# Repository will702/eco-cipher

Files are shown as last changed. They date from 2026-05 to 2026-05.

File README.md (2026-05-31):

# Eco-Cipher Edge Verifier

Eco-Cipher Edge Verifier is a prototype hardware-to-platform package for turning factory waste, emission, and energy readings into trusted digital evidence.

The repository contains the full demo stack:

- Hardware blueprint and wiring specs for an ESP32 edge device.
- Arduino firmware for local sensor reading, validation, hashing, and upload.
- CAD and enclosure assets for the physical verifier.
- A Vite React dashboard that explains the proof flow, hardware, matching, settlement, and reporting story.
- Documentation for IoT behavior, ERP integration, and dashboard operation.

## System Flow

```text
Wastewater / emission / energy sample
-> Sensors
-> ESP32 Edge Verifier
-> Local validation
-> OLED, LEDs, buzzer
-> Hashed JSON payload
-> Backend / dashboard
-> Proof ledger
-> AI matchmaker
-> Settlement and reporting
-> ERP adapter
```

The device is designed to make the physical stream auditable before Eco-Cipher uses it for AI matching or compliance reporting.

## Repository Structure

| Path | Purpose |
|---|---|
| `context/` | Source specification: hardware blueprint, wiring, validation rules, payload schema, CAD dimensions, demo flow, and shopping list |
| `firmware/EcoCipherEdgeVerifier/` | ESP32 Arduino firmware |
| `cad/` | OpenSCAD and FreeCAD source/generator files |
| `cad/generated/` | Generated CAD outputs when present |
| `dashboard/` | Vite React dashboard |
| `dashboard/src/` | Dashboard application source |
| `dashboard/public/models/` | Static 3D model assets for the hardware view |
| `docs/` | Human-readable system documentation |
| `PRODUCT.md` | Product context for the dashboard and demo story |
| `DESIGN.md` | Design direction for the dashboard interface |

## Documentation

Start with these docs depending on what you need:

| Document | Use it for |
|---|---|
| [`docs/iot-system-overview.md`](docs/iot-system-overview.md) | Understanding the ESP32 device, sensors, validation, payload, hash, and upload flow |
| [`docs/erp-integration-flow.md`](docs/erp-integration-flow.md) | Understanding how Eco-Cipher should connect to ERP through a backend adapter |
| [`docs/dashboard-flow.md`](docs/dashboard-flow.md) | Understanding the dashboard views, proof stages, scenarios, and operator flow |
| [`context/README.md`](context/README.md) | Original hardware blueprint package overview |
| [`context/04_payload_schema.json`](context/04_payload_schema.json) | Current example payload shape |

## Hardware Summary

The MVP Edge Verifier uses:

- ESP32 DevKit V1
- pH sensor
- Turbidity sensor
- Water flow sensor
- DS18B20 waterproof temperature sensor
- Optional MQ-135 gas sensor
- Optional ACS712/PZEM current or energy sensor
- OLED I2C display
- Green, yellow, and red LEDs
- Buzzer
- Push button
- Industrial enclosure and pipe/sample chamber demo setup

The ESP32 classifies readings into:

| Status | Meaning | Local output |
|---|---|---|
| `VERIFIED` | Sensor readings are inside the clean demo band | Green LED, buzzer off |
| `WARNING` | Readings are usable but carry caution | Yellow LED, short beep |
| `ANOMALY` | Severe threshold breach, zero flow, sensor risk, or missing context | Red LED, repeated buzzer |

## Dashboard

The dashboard is a Vite React application in `dashboard/`. It simulates the platform view of the device and includes:

- proof-stage walkthrough: Sense, Validate, Hash, Upload, Match, Report
- live sensor-style values and status classification
- mock upload payload
- proof ledger/evidence views
- CAD-backed hardware inspection view
- AI receiver matching
- exchange/settlement consequence
- compliance and MRV-style reporting output

Available dashboard views:

```text
overview
edge-ai
hardware
matchmaker
zkgrid
exchange
proofs
reports
```

The hardware view is directly addressable with:

```text
http://127.0.0.1:5173/?view=hardware
```

## Development Commands

Run repository shell commands through `rtk`.

Dashboard commands are run from `dashboard/`:

```bash
rtk bun install
rtk bun run dev --host 127.0.0.1
rtk bun run build
rtk bun run preview
```

If the local shell picks an old Node runtime, use Node 22 before running Bun/Vite commands. A previously verified local Node path was:

```bash
/Users/willson/.nvm/versions/node/v22.21.1/bin
```

## Firmware

Firmware lives at:

```text
firmware/EcoCipherEdgeVerifier/EcoCipherEdgeVerifier.ino
```

The sketch:

- reads pH, turbidity, flow, temperature, gas, and energy/current context
- calculates status and quality scores
- generates `payload_hash` using SHA-256
- updates OLED, LEDs, and buzzer
- posts JSON to the configured API endpoint

Compile it with Arduino IDE or `arduino-cli` using the ESP32 board package and the required sensor/display libraries.

## CAD

CAD source files live in `cad/`. FreeCAD output can be regenerated when FreeCAD is installed:

```bash
rtk /Applications/FreeCAD.app/Contents/Resources/bin/freecadcmd cad/eco_cipher_freecad_model.py
```

Keep generated CAD artifacts scoped to `cad/generated/`.

## ERP Integration Position

ERP integration should happen through a backend adapter, not directly from the ESP32 or browser UI.

Recommended boundary:

```text
Device payload
-> Eco-Cipher ingestion API
-> validation/proof service
-> ERP adapter
-> ERP records
```

Typical ERP outputs include:

- IoT measurement event
- waste batch or material lot
- quality inspection record
- nonconformance or exception ticket
- receiver recommendation
- transfer or recycling order
- settlement or credit event
- ESG/MRV/compliance report line

See [`docs/erp-integration-flow.md`](docs/erp-integration-flow.md) for the detailed mapping.

## Verification

Minimum checks by subsystem:

| Subsystem | Verification |
|---|---|
| Dashboard | `rtk bun run build` from `dashboard/` |
| Firmware | Compile with Arduino IDE or `arduino-cli` for ESP32 |
| CAD | Regenerate FreeCAD/OpenSCAD outputs and inspect STL/STEP files |
| Docs | Review Markdown rendering and links |

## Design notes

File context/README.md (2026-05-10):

# Eco-Cipher Edge Verifier — Hardware Blueprint Package

This package contains a complete hardware prototype blueprint for **Eco-Cipher Edge Verifier**, the IoT-based physical trust layer for the Eco-Cipher platform.

## Prototype Purpose

Eco-Cipher Edge Verifier captures physical waste/environmental data from industrial output points, validates readings locally at the edge, then sends hashed verified payloads to the Eco-Cipher AI + privacy layer.

## Core MVP Stack

- ESP32 DevKit V1
- pH sensor module
- Turbidity sensor
- Water flow sensor
- DS18B20 waterproof temperature sensor
- OLED I2C display
- Green/yellow/red LED indicators
- Buzzer
- Push button
- Industrial-style enclosure
- Pipe/sample chamber demo setup

## Recommended Build Order

1. Assemble ESP32 + OLED + LEDs.
2. Add pH and turbidity sensors.
3. Add flow sensor and temperature sensor.
4. Implement edge validation rules.
5. Send JSON payload to backend.
6. Generate payload hash.
7. Create CAD enclosure render.
8. Build dashboard integration.
9. Record demo video.
10. Insert photos/renders into BRICS slide deck.

## Final Prototype Statement

Eco-Cipher Edge Verifier is the physical trust layer that verifies waste, energy, and carbon-related data directly from industrial processes before the AI matchmaker and privacy-preserving transaction layer process it.

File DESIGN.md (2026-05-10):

# Eco-Cipher Design Context

## Design Strategy

Use a restrained product UI with industrial neutrals, safety-state color, and clear proof-stage hierarchy. Non-technical users should be able to follow the story in this order: physical reading, local decision, tamper-evident hash, receiver match, proof/report outcome.

## Color

- Canvas: tinted light neutral, not pure white.
- Ink: charcoal/slate neutral, not pure black.
- Verified: muted green.
- Warning: ochre/amber.
- Anomaly: controlled red.
- Accent: rust/safety orange, reserved for active navigation, page transitions, and primary actions.

## Typography

Use a practical sans-serif UI stack for readability and a monospace stack for hashes, pins, scores, and payload fragments. Avoid decorative display type in dashboard controls.

## Components

- Navigation buttons must include a plain-language destination hint and selected-state feedback.
- Scenario buttons must explain what the sample means before the user clicks.
- Status panels should show both machine labels and human meaning.
- Loading, retry, and empty states should be written for a demo audience, not only engineers.

## Motion

Motion should confirm state changes: page switching, proof-stage progress, CAD loading, and button activation. Keep transitions short and respect `prefers-reduced-motion`.

## Responsive Behavior

Desktop can use a persistent left rail and multi-column proof workspace. Tablet and mobile should collapse to a single-column flow with horizontal navigation where needed and no hidden content.

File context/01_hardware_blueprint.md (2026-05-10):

# Eco-Cipher Edge Verifier — Full Hardware Blueprint

## 1. Hardware Architecture

```text
Wastewater / Emission / Energy Sample
        ↓
Sensor Modules
        ↓
ESP32 Edge Controller
        ↓
Edge Validation Logic
        ↓
Local Output: OLED + LED + Buzzer
        ↓
Wireless Transmission: Wi-Fi / MQTT / HTTP
        ↓
Backend / Dashboard
        ↓
AI Matchmaker + ZK Hash Layer
```

## 2. Recommended MVP Hardware

| Component | Purpose |
|---|---|
| ESP32 DevKit V1 | Main controller and Wi-Fi communication |
| pH sensor | Measures acidity/alkalinity of wastewater |
| Turbidity sensor | Measures cloudiness/contamination |
| Water flow sensor | Measures flow rate and estimated volume |
| DS18B20 waterproof sensor | Measures liquid temperature |
| OLED I2C display | Shows live values and status |
| Green LED | Verified status |
| Yellow LED | Warning status |
| Red LED | Anomaly status |
| Buzzer | Alert for anomaly |
| Push button | Manual calibration/demo trigger |

## 3. Physical Demo Layout

```text
[Water Container A]
      ↓
[Pipe / Tube]
      ↓
[Flow Sensor]
      ↓
[pH Probe + Turbidity Sensor Zone]
      ↓
[Output Container]

Nearby:
[Eco-Cipher Edge Verifier Box]
ESP32 + OLED + LED + Buzzer
```

## 4. Core Device Function

The device performs:

1. Sensor acquisition.
2. Edge validation.
3. Local status display.
4. Payload generation.
5. Hash generation.
6. Backend transmission.

## 5. Pitch Explanation

The Eco-Cipher Edge Verifier is installed near a factory’s waste output line. It captures pH, turbidity, flow, and temperature data directly from the physical waste stream. The ESP32 performs edge-level validation to detect abnormal readings or manipulation attempts. Verified data is packaged into a hashed payload and sent to the Eco-Cipher platform as trusted input for AI matchmaking and privacy-preserving exchange.

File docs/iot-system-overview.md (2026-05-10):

# Eco-Cipher IoT Overview

Eco-Cipher uses an edge device called the Edge Verifier to read what is happening in the real world at the factory line. It measures the sample, checks whether the reading looks normal, and sends the result to the platform.

## In Simple Terms

```text
Factory sample
-> Sensors
-> ESP32 device
-> Local check
-> Status light and buzzer
-> Hashed payload
-> Dashboard and backend
```

The device looks at things like:

- pH
- turbidity
- flow
- temperature
- gas risk
- energy or current context

## What The Device Does

The device has three jobs:

1. Read the sensors.
2. Decide whether the stream looks `VERIFIED`, `WARNING`, or `ANOMALY`.
3. Send a digital payload with a hash so the record can be checked later.

It also shows the result locally with:

- a green light for verified
- a yellow light for warning
- a red light and buzzer for anomaly

## Why This Matters

The IoT device is the point where physical evidence becomes digital evidence. That is important because the dashboard and ERP should not guess what happened at the source. They should receive a trusted reading from the edge device.

## What Gets Sent

Each reading becomes one small JSON report with the device ID, factory name, sensor values, status, quality score, and payload hash.

That hash is the fingerprint of the reading. It helps the platform prove that the data has not changed.

## Bottom Line

Eco-Cipher IoT is a trust layer at the edge. It reads the factory signal, checks it locally, and sends a verified record to the rest of the system.

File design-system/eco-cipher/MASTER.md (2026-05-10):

# Design System Master File

> **LOGIC:** When building a specific page, first check `design-system/pages/[page-name].md`.
> If that file exists, its rules **override** this Master file.
> If not, strictly follow the rules below.

---

**Project:** Eco-Cipher
**Generated:** 2026-05-07 00:02:41
**Category:** Financial Dashboard

---

## Global Rules

### Color Palette

| Role | Hex | CSS Variable |
|---|-----|---|
| Primary | `#64748B` | `--color-primary` |
| Secondary | `#94A3B8` | `--color-secondary` |
| CTA/Accent | `#F97316` | `--color-cta` |
| Background | `#F8FAFC` | `--color-background` |
| Text | `#334155` | `--color-text` |

**Color Notes:** Industrial grey + safety orange

### Typography

- **Heading Font:** Cormorant
- **Body Font:** Montserrat
- **Mood:** luxury, high-end, fashion, elegant, refined, premium
- **Google Fonts:** [Cormorant + Montserrat](https://fonts.google.com/share?selection.family=Cormorant:wght@400;500;600;700|Montserrat:wght@300;400;500;600;700)

**CSS Import:**
```css
@import url('https://fonts.googleapis.com/css2?family=Cormorant:wght@400;500;600;700&family=Montserrat:wght@300;400;500;600;700&display=swap');
```

### Spacing Variables

| Token | Value | Usage |
|---|---|---|
| `--space-xs` | `4px` / `0.25rem` | Tight gaps |
| `--space-sm` | `8px` / `0.5rem` | Icon gaps, inline spacing |
| `--space-md` | `16px` / `1rem` | Standard padding |
| `--space-lg` | `24px` / `1.5rem` | Section padding |
| `--space-xl` | `32px` / `2rem` | Large gaps |
| `--space-2xl` | `48px` / `3rem` | Section margins |
| `--space-3xl` | `64px` / `4rem` | Hero padding |

### Shadow Depths

| Level | Value | Usage |
|---|---|---|
| `--shadow-sm` | `0 1px 2px rgba(0,0,0,0.05)` | Subtle lift |
| `--shadow-md` | `0 4px 6px rgba(0,0,0,0.1)` | Cards, buttons |
| `--shadow-lg` | `0 10px 15px rgba(0,0,0,0.1)` | Modals, dropdowns |
| `--shadow-xl` | `0 20px 25px rgba(0,0,0,0.15)` | Hero images, featured cards |

---

## Component Specs

### Buttons

```css
/* Primary Button */
.btn-primary {
  background: #F97316;
  color: white;
  padding: 12px 24px;
  border-radius: 8px;
  font-weight: 600;
  transition: all 200ms ease;
  cursor: pointer;
}

.btn-primary:hover {
  opacity: 0.9;
  transform: translateY(-1px);
}

/* Secondary Button */
.btn-secondary {
  background: transparent;
  color: #64748B;
  border: 2px solid #64748B;
  padding: 12px 24px;
  border-radius: 8px;
  font-weight: 600;
  transition: all 200ms ease;
  cursor: pointer;
}
```

### Cards

```css
.card {
  background: #F8FAFC;
  border-radius: 12px;
  padding: 24px;
  box-shadow: var(--shadow-md);
  transition: all 200ms ease;
  cursor: pointer;
}

.card:hover {
  box-shadow: var(--shadow-lg);
  transform: translateY(-2px);
}
```

### Inputs

```css
.input {
  padding: 12px 16px;
  border: 1px solid #E2E8F0;
  border-radius: 8px;
  font-size: 16px;
  transition: border-color 200ms ease;
}

.input:focus {
  border-color: #64748B;
  outline: none;
  box-shadow: 0 0 0 3px #64748B20;
}
```

### Modals

```css
.modal-overlay {
  background: rgba(0, 0, 0, 0.5);
  backdrop-filter: blur(4px);
}

.modal {
  background: white;
  border-radius: 16px;
  padding: 32px;
  box-shadow: var(--shadow-xl);
  max-width: 500px;
  width: 90%;
}
```

---

## Style Guidelines

**Style:** Dark Mode (OLED)

**Keywords:** Dark theme, low light, high contrast, deep black, midnight blue, eye-friendly, OLED, night mode, power efficient

**Best For:** Night-mode apps, coding platforms, entertainment, eye-strain prevention, OLED devices, low-light

**Key Effects:** Minimal glow (text-shadow: 0 0 10px), dark-to-light transitions, low white emission, high readability, visible focus

### Page Pattern

**Pattern Name:** Horizontal Scroll Journey

- **Conversion Strategy:** Immersive product discovery. High engagement. Keep navigation visible.
28,Bento Grid Showcase,bento,  grid,  features,  modular,  apple-style,  showcase", 1. Hero, 2. Bento Grid (Key Features), 3. Detail Cards, 4. Tech Specs, 5. CTA, Floating Action Button or Bottom of Grid, Card backgrounds: #F5F5F7 or Glass. Icons: Vibrant brand colors. Text: Dark., Hover card scale (1.02), video inside cards, tilt effect, staggered reveal, Scannable value props. High information density without clutter. Mobile stack.
29,Interactive 3D Configurator,3d,  configurator,  customizer,  interactive,  product", 1. Hero (Configurator), 2. Feature Highlight (synced), 3. Price/Specs, 4. Purchase, Inside Configurator UI + Sticky Bottom Bar, Neutral studio background. Product: Realistic materials. UI: Minimal overlay., Real-time rendering, material swap animation, camera rotate/zoom, light reflection, Increases ownership feeling. 360 view reduces return rates. Direct add-to-cart.
30,AI-Driven Dynamic Landing,ai,  dynamic,  personalized,  adaptive,  generative", 1. Prompt/Input Hero, 2. Generated Result Preview, 3. How it Works, 4. Value Prop, Input Field (Hero) + 'Try it' Buttons, Adaptive to user input. Dark mode for compute feel. Neon accents., Typing text effects, shimmering generation loaders, morphing layouts, Immediate value demonstration. 'Show, don't tell'. Low friction start.
- **CTA Placement:** Floating Sticky CTA or End of Horizontal Track
- **Section Order:** 1. Intro (Vertical), 2. The Journey (Horizontal Track), 3. Detail Reveal, 4. Vertical Footer

---

## Anti-Patterns (Do NOT Use)

- ❌ Light mode default
- ❌ Slow rendering

### Additional Forbidden Patterns

- ❌ **Emojis as icons** — Use SVG icons (Heroicons, Lucide, Simple Icons)
- ❌ **Missing cursor:pointer** — All clickable elements must have cursor:pointer
- ❌ **Layout-shifting hovers** — Avoid scale transforms that shift layout
- ❌ **Low contrast text** — Maintain 4.5:1 minimum contrast ratio
- ❌ **Instant state changes** — Always use transitions (150-300ms)
- ❌ **Invisible focus states** — Focus states must be visible for a11y

---

## Pre-Delivery Checklist

Before delivering any UI code, verify:

- [ ] No emojis used as icons (use SVG instead)
- [ ] All icons from consistent icon set (Heroicons/Lucide)
- [ ] `cursor-pointer` on all clickable elements
- [ ] Hover states with smooth transitions (150-300ms)
- [ ] Light mode: text contrast 4.5:1 minimum
- [ ] Focus states visible for keyboard navigation
- [ ] `prefers-reduced-motion` respected
- [ ] Responsive: 375px, 768px, 1024px, 1440px
- [ ] No content hidden behind fixed navbars
- [ ] No horizontal scroll on mobile

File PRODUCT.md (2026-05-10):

# Eco-Cipher Product Context

## Register

product

## Product Purpose

Eco-Cipher is a prototype platform that explains how factory waste, emissions, and energy readings become trusted digital evidence. The dashboard connects the physical Edge Verifier device, local ESP32 validation, payload hashing, AI receiver matching, proof records, smart-contract settlement, and CBAM-style reporting.

## Primary Users

- Non-technical pitch audiences who need to understand the proof story quickly.
- Operators inspecting demo sensor states and device behavior.
- Founders, reviewers, and partners evaluating whether the hardware-to-platform flow is credible.

## Core Jobs

- Show what the Edge Verifier senses and why the status becomes verified, warning, or anomaly.
- Make every navigation button feel like a page switch with clear feedback.
- Explain technical ideas in plain language without hiding the real data model.
- Keep the CAD/hardware view connected to the same proof-stage story as the dashboard.

## Tone

Industrial, credible, calm, and demo-ready. The interface should feel like a product control room for a physical prototype, not a generic SaaS landing page.

## Anti-References

- Decorative crypto/neon visuals.
- Dense technical jargon without plain-language explanation.
- Generic card grids where every panel looks equally important.
- UI controls that do not visibly confirm what changed.

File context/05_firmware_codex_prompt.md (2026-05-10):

# Codex Prompt — ESP32 Firmware

```text
Create ESP32 Arduino firmware for Eco-Cipher Edge Verifier.

Hardware:
- ESP32 DevKit V1
- pH sensor on GPIO34 analog
- turbidity sensor on GPIO35 analog
- water flow sensor on GPIO27 interrupt
- DS18B20 temperature sensor on GPIO4
- OLED I2C SDA GPIO21, SCL GPIO22
- green LED GPIO16
- yellow LED GPIO17
- red LED GPIO18
- buzzer GPIO19
- button GPIO25

Firmware requirements:
- Connect to Wi-Fi
- Read all sensors every 5 seconds
- Calculate flow rate and total volume
- Classify status as VERIFIED, WARNING, or ANOMALY
- Display values on OLED
- Turn on LED based on status
- Beep buzzer for anomaly
- Create JSON payload
- Generate a SHA256 hash from the payload
- Send payload to an HTTP endpoint
- Add clean modular functions and comments
- Include placeholder constants for Wi-Fi SSID, password, and API endpoint
- Make the code easy to modify for Supabase/Firebase/Node backend
```

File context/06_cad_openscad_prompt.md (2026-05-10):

# Codex Prompt — OpenSCAD CAD

```text
Create an OpenSCAD model for Eco-Cipher Edge Verifier.

Requirements:
- Industrial IoT enclosure
- Size 120mm x 80mm x 40mm
- Wall thickness 3mm
- Removable lid
- Four M3 screw holes
- Four internal ESP32 mounting posts
- Front OLED cutout
- Three LED holes labeled VALID, WARNING, ANOMALY
- Side ports labeled PWR, PH, TURB, FLOW, TEMP
- Top engraved label: ECO-CIPHER EDGE VERIFIER
- Small QR/device ID plate area
- Add mounting tabs
- Keep everything parametric
- Make it 3D-printable
- Add comments explaining each module
- Split into modules: body(), lid(), mounting_posts(), front_panel_cutouts(), side_ports(), mounting_tabs()
```

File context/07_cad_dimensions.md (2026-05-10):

# CAD Dimensions and Mechanical Notes

## Main Enclosure

```text
Length: 120 mm
Width: 80 mm
Height: 40 mm
Wall thickness: 3 mm
Lid thickness: 3 mm
Screw hole: M3
Mounting posts: 4
```

## Front Panel

Must include:
- OLED display cutout
- 3 LED holes
- Device label
- QR/device ID sticker zone

Suggested layout:

```text
┌────────────────────────────┐
│ ECO-CIPHER EDGE VERIFIER   │
│ ┌──────────────┐           │
│ │ OLED SCREEN  │           │
│ └──────────────┘           │
│ ● VALID ● WARN ● ANOMALY   │
│ ID: EC-EDGE-001            │
└────────────────────────────┘
```

## Side Panel Ports

```text
PWR
PH
TURB
FLOW
TEMP
```

## Industrial Styling

- Rounded corners
- Mounting tabs
- Cable gland holes
- Visible screw heads
- QR/device ID area
- Label: SENSOR IN → VERIFIED DATA OUT

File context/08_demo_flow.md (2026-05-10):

# Demo Flow — Eco-Cipher Edge Verifier

## Scenario

Anonymous Wastewater Exchange with Carbon Impact Recommendation.

Factory A produces wastewater. The Edge Verifier reads physical parameters and sends verified data to Eco-Cipher. The AI matchmaker identifies Factory B as a compatible receiver. The platform displays a verified, privacy-preserving match.

## Demo Sequence

### Step 1 — Boot

OLED:
```text
BOOTING...
Eco-Cipher Edge
```

### Step 2 — Connect

OLED:
```text
WiFi Connected
Device: EC-EDGE-001
```

### Step 3 — Read

Put sensor into sample liquid.

OLED:
```text
Reading sensors...
```

### Step 4 — Validate

LED status:
```text
Green = verified
Yellow = warning
Red = anomaly
```

### Step 5 — Upload

OLED:
```text
Payload uploaded
Hash generated
```

### Step 6 — Dashboard

Dashboard:
```text
Factory A stream verified
AI match found
Carbon impact estimated
```

## Demo Samples

| Sample | Composition | Expected Result |
|---|---|---|
| A | Clear water | Verified stream |
| B | Water + tea/coffee | Organic/turbid waste |
| C | Water + vinegar/soap | Warning/anomaly |

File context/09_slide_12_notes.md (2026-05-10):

# Slide 12 Notes — IoT Hardware Showcase

## Slide Title

Eco-Cipher Edge Verifier: Physical Trust Layer

## Suggested Layout

Left side:
- Photo/CAD of device
- Labeled hardware components

Right side:
- Sensor → ESP32 → Edge Validation → Backend
- 3 key bullets:
  1. Captures physical waste parameters
  2. Performs edge-level anomaly detection
  3. Sends hashed verified payloads to Eco-Cipher AI

## Caption

The device prevents manual greenwashing by verifying waste data directly from industrial output points.

## Hardware-to-Software Mapping

| Hardware Data | Software Meaning | AI Use |
|---|---|---|
| pH | Chemical characteristic | Waste classification |
| Turbidity | Contamination level | Processing suitability |
| Flow rate | Quantity / volume | Exchange feasibility |
| Temperature | Process condition | Validity context |
| Edge status | Trust level | Match confidence |
| Payload hash | Audit proof | ZK/smart contract reference |

## Pitch Script

The Eco-Cipher Edge Verifier is installed near a factory’s waste output line. It uses pH, turbidity, flow, and temperature sensors to capture real physical data. The ESP32 validates these readings at the edge, detects anomalies, and sends a hashed payload to the Eco-Cipher platform. This turns physical industrial output into trusted input for AI matchmaking and privacy-preserving carbon or material exchange.

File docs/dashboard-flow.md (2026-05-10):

# Eco-Cipher Dashboard Flow

The dashboard is the screen that explains the whole Eco-Cipher story. It shows the device reading, the proof state, the receiver match, and the report outcome.

## Main Story

```text
Sense
-> Validate
-> Hash
-> Upload
-> Match
-> Report
```

That is the normal flow when the sample looks good. If the reading is bad, the dashboard still keeps the evidence, but it blocks or holds the later steps.

## What The Dashboard Shows

- the live device state
- the current sensor values
- the payload hash
- the proof record
- the receiver match
- the settlement result
- the reporting result

## Main Views

- `Overview` shows the full story.
- `Edge Verify` shows how the device decides locally.
- `Hardware CAD` shows the physical device in 3D.
- `AI Matchmaker` shows which receiver fits best.
- `Proof Ledger` shows the public proof record.
- `Settlement` shows the exchange result.
- `Evidence` shows the current hash and proof state.
- `Reports` shows the compliance output.

## How People Use It

The dashboard has two common modes:

- guided mode for demos and presentations
- manual mode for checking sensor changes and operator decisions

It also has preset sample scenarios, such as clean water, organic turbidity, anomaly, emission risk, and energy context.

## Bottom Line

The dashboard is the place where Eco-Cipher makes the system easy to understand. It connects the physical device to the proof trail, the matching logic, and the final report.

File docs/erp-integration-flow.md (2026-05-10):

# Eco-Cipher ERP Integration

Eco-Cipher should connect to ERP through the backend, not straight from the sensor or the dashboard button.

## Simple Flow

```text
Edge device
-> Eco-Cipher backend
-> Proof check
-> ERP adapter
-> ERP record
```

## What The ERP Needs

The ERP system does not need the full sensor story. It needs business-ready records such as:

- a measurement event
- a waste batch or material lot
- an inspection result
- an exception ticket
- a receiver recommendation
- a transfer or recycling order
- a settlement or credit event
- a compliance report line

## How Status Changes ERP Behavior

- `VERIFIED` means the reading can move forward.
- `WARNING` means the reading can move forward, but with caution and operator review if needed.
- `ANOMALY` means the reading should be held, quarantined, or sent to manual review.

## Why The Backend Matters

The backend is the place where Eco-Cipher checks the payload, stores the hash, and decides what is safe to pass on. ERP should only receive the approved result, not raw UI state.

## Bottom Line

ERP is where Eco-Cipher turns trusted evidence into business action. The edge device creates the evidence, the backend validates it, and the ERP system records the outcome.

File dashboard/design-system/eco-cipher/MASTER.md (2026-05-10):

# Design System Master File

> **LOGIC:** When building a specific page, first check `design-system/pages/[page-name].md`.
> If that file exists, its rules **override** this Master file.
> If not, strictly follow the rules below.

---

**Project:** Eco-Cipher
**Generated:** 2026-05-05 03:05:42
**Category:** Smart Home/IoT Dashboard

---

## Global Rules

### Color Palette

| Role | Hex | CSS Variable |
|---|-----|---|
| Primary | `#64748B` | `--color-primary` |
| Secondary | `#94A3B8` | `--color-secondary` |
| CTA/Accent | `#F97316` | `--color-cta` |
| Background | `#F8FAFC` | `--color-background` |
| Text | `#334155` | `--color-text` |

**Color Notes:** Industrial grey + safety orange

### Typography

- **Heading Font:** Fira Code
- **Body Font:** Fira Sans
- **Mood:** dashboard, data, analytics, code, technical, precise
- **Google Fonts:** [Fira Code + Fira Sans](https://fonts.google.com/share?selection.family=Fira+Code:wght@400;500;600;700|Fira+Sans:wght@300;400;500;600;700)

**CSS Import:**
```css
@import url('https://fonts.googleapis.com/css2?family=Fira+Code:wght@400;500;600;700&family=Fira+Sans:wght@300;400;500;600;700&display=swap');
```

### Spacing Variables

| Token | Value | Usage |
|---|---|---|
| `--space-xs` | `4px` / `0.25rem` | Tight gaps |
| `--space-sm` | `8px` / `0.5rem` | Icon gaps, inline spacing |
| `--space-md` | `16px` / `1rem` | Standard padding |
| `--space-lg` | `24px` / `1.5rem` | Section padding |
| `--space-xl` | `32px` / `2rem` | Large gaps |
| `--space-2xl` | `48px` / `3rem` | Section margins |
| `--space-3xl` | `64px` / `4rem` | Hero padding |

### Shadow Depths

| Level | Value | Usage |
|---|---|---|
| `--shadow-sm` | `0 1px 2px rgba(0,0,0,0.05)` | Subtle lift |
| `--shadow-md` | `0 4px 6px rgba(0,0,0,0.1)` | Cards, buttons |
| `--shadow-lg` | `0 10px 15px rgba(0,0,0,0.1)` | Modals, dropdowns |
| `--shadow-xl` | `0 20px 25px rgba(0,0,0,0.15)` | Hero images, featured cards |

---

## Component Specs

### Buttons

```css
/* Primary Button */
.btn-primary {
  background: #F97316;
  color: white;
  padding: 12px 24px;
  border-radius: 8px;
  font-weight: 600;
  transition: all 200ms ease;
  cursor: pointer;
}

.btn-primary:hover {
  opacity: 0.9;
  transform: translateY(-1px);
}

/* Secondary Button */
.btn-secondary {
  background: transparent;
  color: #64748B;
  border: 2px solid #64748B;
  padding: 12px 24px;
  border-radius: 8px;
  font-weight: 600;
  transition: all 200ms ease;
  cursor: pointer;
}
```

### Cards

```css
.card {
  background: #F8FAFC;
  border-radius: 12px;
  padding: 24px;
  box-shadow: var(--shadow-md);
  transition: all 200ms ease;
  cursor: pointer;
}

.card:hover {
  box-shadow: var(--shadow-lg);
  transform: translateY(-2px);
}
```

### Inputs

```css
.input {
  padding: 12px 16px;
  border: 1px solid #E2E8F0;
  border-radius: 8px;
  font-size: 16px;
  transition: border-color 200ms ease;
}

.input:focus {
  border-color: #64748B;
  outline: none;
  box-shadow: 0 0 0 3px #64748B20;
}
```

### Modals

```css
.modal-overlay {
  background: rgba(0, 0, 0, 0.5);
  backdrop-filter: blur(4px);
}

.modal {
  background: white;
  border-radius: 16px;
  padding: 32px;
  box-shadow: var(--shadow-xl);
  max-width: 500px;
  width: 90%;
}
```

---

## Style Guidelines

**Style:** Dark Mode (OLED)

**Keywords:** Dark theme, low light, high contrast, deep black, midnight blue, eye-friendly, OLED, night mode, power efficient

**Best For:** Night-mode apps, coding platforms, entertainment, eye-strain prevention, OLED devices, low-light

**Key Effects:** Minimal glow (text-shadow: 0 0 10px), dark-to-light transitions, low white emission, high readability, visible focus

### Page Pattern

**Pattern Name:** Hero + Testimonials + CTA

- **Conversion Strategy:** Social proof before CTA. Use 3-5 testimonials. Include photo + name + role. CTA after social proof.
- **CTA Placement:** Hero (sticky) + Post-testimonials
- **Section Order:** 1. Hero, 2. Problem statement, 3. Solution overview, 4. Testimonials carousel, 5. CTA

---

## Anti-Patterns (Do NOT Use)

- ❌ Slow updates
- ❌ No automation

### Additional Forbidden Patterns

- ❌ **Emojis as icons** — Use SVG icons (Heroicons, Lucide, Simple Icons)
- ❌ **Missing cursor:pointer** — All clickable elements must have cursor:pointer
- ❌ **Layout-shifting hovers** — Avoid scale transforms that shift layout
- ❌ **Low contrast text** — Maintain 4.5:1 minimum contrast ratio
- ❌ **Instant state changes** — Always use transitions (150-300ms)
- ❌ **Invisible focus states** — Focus states must be visible for a11y

---

## Pre-Delivery Checklist

Before delivering any UI code, verify:

- [ ] No emojis used as icons (use SVG instead)
- [ ] All icons from consistent icon set (Heroicons/Lucide)
- [ ] `cursor-pointer` on all clickable elements
- [ ] Hover states with smooth transitions (150-300ms)
- [ ] Light mode: text contrast 4.5:1 minimum
- [ ] Focus states visible for keyboard navigation
- [ ] `prefers-reduced-motion` respected
- [ ] Responsive: 375px, 768px, 1024px, 1440px
- [ ] No content hidden behind fixed navbars
- [ ] No horizontal scroll on mobile

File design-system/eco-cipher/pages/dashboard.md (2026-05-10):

# Dashboard Page Overrides

> **PROJECT:** Eco-Cipher
> **Generated:** 2026-05-07 00:02:41
> **Page Type:** Dashboard / Data View

> ⚠️ **IMPORTANT:** Rules in this file **override** the Master file (`design-system/MASTER.md`).
> Only deviations from the Master are documented here. For all other rules, refer to the Master.

---

## Page-Specific Rules

### Layout Overrides

- **Max Width:** 800px (narrow, focused)
- **Layout:** Single column, centered
- **Sections:** 1. Intro (Vertical), 2. The Journey (Horizontal Track), 3. Detail Reveal, 4. Vertical Footer

### Spacing Overrides

- **Content Density:** Low — focus on clarity

### Typography Overrides

- No overrides — use Master typography

### Color Overrides

- **Strategy:** Continuous palette transition. Chapter colors. Progress bar #000000.

### Component Overrides

- Avoid: Load 50MB textures
- Avoid: Auto-play high-res video loops

---

## Page-Specific Components

- No unique components for this page

---

## Recommendations

- Effects: KPI value animations (count-up), trend arrow direction animations, metric card hover lift, alert pulse effect
- Sustainability: Compress and lazy load 3D models
- Sustainability: Click-to-play or pause when off-screen
- CTA Placement: Floating Sticky CTA or End of Horizontal Track

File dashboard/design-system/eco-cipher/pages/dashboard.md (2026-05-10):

# Dashboard Page Overrides

> **PROJECT:** Eco-Cipher
> **Generated:** 2026-05-05 03:05:42
> **Page Type:** Dashboard / Data View

> ⚠️ **IMPORTANT:** Rules in this file **override** the Master file (`design-system/MASTER.md`).
> Only deviations from the Master are documented here. For all other rules, refer to the Master.

---

## Page-Specific Rules

### Layout Overrides

- **Max Width:** 1400px or full-width
- **Grid:** 12-column grid for data flexibility
- **Sections:** 1. Hero, 2. Problem statement, 3. Solution overview, 4. Testimonials carousel, 5. CTA

### Spacing Overrides

- **Content Density:** High — optimize for information display

### Typography Overrides

- No overrides — use Master typography

### Color Overrides

- **Strategy:** Hero: Brand color. Testimonials: Light bg #F5F5F5. Quotes: Italic, muted color #666. CTA: Vibrant

### Component Overrides

- No overrides — use Master component specs

---

## Page-Specific Components

- No unique components for this page

---

## Recommendations

- Effects: Real-time chart animations, alert pulse/glow, status indicator blink animation, smooth data stream updates, loading effect
- CTA Placement: Hero (sticky) + Post-testimonials

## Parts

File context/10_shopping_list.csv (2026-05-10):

Category | Component | Quantity | Priority | Notes
Controller | ESP32 DevKit V1 | 1 | Must-have | Main microcontroller with Wi-Fi
Sensor | pH sensor module | 1 | Must-have | Wastewater chemical profile
Sensor | Turbidity sensor | 1 | Must-have | Cloudiness/contamination
Sensor | Water flow sensor YF-S201 | 1 | Must-have | Flow rate and volume
Sensor | DS18B20 waterproof temperature sensor | 1 | Recommended | Process temperature
Display | OLED I2C 0.96 inch | 1 | Must-have | Local status display
Indicator | Green LED | 1 | Must-have | Verified status
Indicator | Yellow LED | 1 | Must-have | Warning status
Indicator | Red LED | 1 | Must-have | Anomaly status
Audio | Active buzzer | 1 | Recommended | Alert signal
Input | Push button | 1 | Recommended | Calibration/demo trigger
Passive | 220 ohm resistor | 3 | Must-have | LED protection
Passive | 4.7k ohm resistor | 1 | Must-have | DS18B20 pull-up
Wiring | Jumper wires | 1 set | Must-have | Connections
Base | Breadboard or perfboard | 1 | Must-have | Prototype wiring
Mechanical | Silicone/PVC tube | 1 | Must-have | Water flow demo
Mechanical | Small water container | 2 | Must-have | Input/output sample
Mechanical | Acrylic/wood base | 1 | Recommended | Demo base
Mechanical | 3D printed enclosure | 1 | Optional | Professional look
Optional | MQ-135 gas sensor | 1 | Optional | Emission simulation
Optional | PZEM-004T or ACS712 | 1 | Optional | Energy/carbon logic

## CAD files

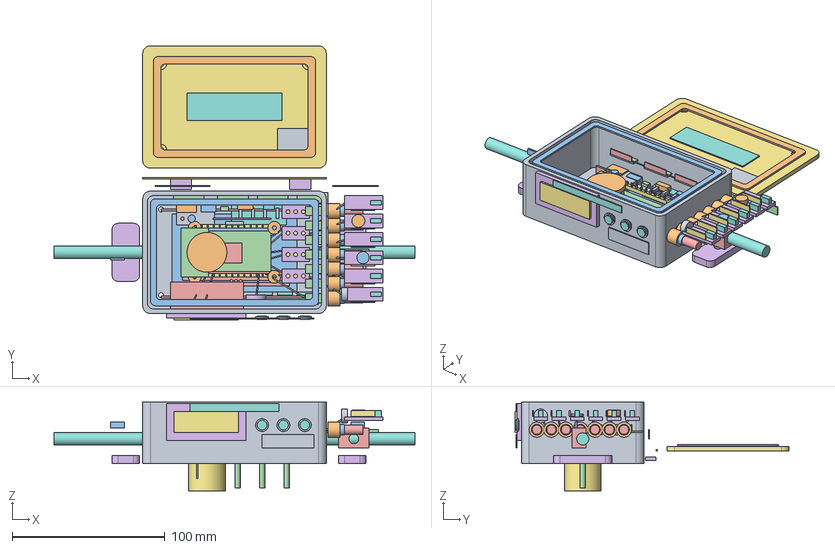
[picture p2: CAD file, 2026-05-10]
cad/generated/eco_cipher_edge_verifier_detailed.step
236.0 x 179.4 x 58.0 mm
Enclosure_body___hollow_ABS_shell
ESP32_M2_5_standoff
ESP32_M2_5_standoff001
ESP32_M2_5_standoff002
ESP32_M2_5_standoff003
Raised_gasket_channel
Wet_dry_zone_divider_wall
Internal_enclosure_stiffening_rib
Internal_enclosure_stiffening_rib001
Raised_enclosure_foot_pad
Raised_enclosure_foot_pad001
Removable_lid_with_countersunk_screw_recesses
Raised_top_device_label_plate
QR_and_device_ID_sticker_plate
Lid_silicone_gasket_insert
Internal_perfboard_carrier
ESP32_DevKit_V1_board
ESP32_metal_RF_shield
ESP32_USB_connector
ESP32_black_pin_header_rail
ESP32_gold_header_pin
ESP32_gold_header_pin001
ESP32_gold_header_pin002
ESP32_gold_header_pin003
ESP32_gold_header_pin004
ESP32_gold_header_pin005
ESP32_gold_header_pin006
ESP32_gold_header_pin007
ESP32_gold_header_pin008
ESP32_gold_header_pin009
ESP32_gold_header_pin010
ESP32_gold_header_pin011
ESP32_black_pin_header_rail001
ESP32_gold_header_pin012
ESP32_gold_header_pin013
ESP32_gold_header_pin014
ESP32_gold_header_pin015
ESP32_gold_header_pin016
ESP32_gold_header_pin017
ESP32_gold_header_pin018
ESP32_gold_header_pin019
ESP32_gold_header_pin020
ESP32_gold_header_pin021
ESP32_gold_header_pin022
ESP32_gold_header_pin023
_5V_to_3V3_buck_converter
Power_entry_fuse_holder
Power_switch_rocker
Power_entry_TVS_ESD_diode_marker
_5V_power_rail_red
GND_power_rail_black
_3V3_protected_rail_orange
PH_TURB_terminal_block
PH_TURB_terminal_block_screw_clamp
PH_TURB_terminal_block_screw_clamp001
PH_TURB_terminal_block_screw_clamp002
FLOW_TEMP_terminal_block
FLOW_TEMP_terminal_block_screw_clamp
FLOW_TEMP_terminal_block_screw_clamp001
FLOW_TEMP_terminal_block_screw_clamp002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

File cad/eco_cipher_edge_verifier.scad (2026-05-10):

// Eco-Cipher Edge Verifier parametric enclosure.
// Render body() and lid() separately for print preparation if needed.

$fn = 48;

length_mm = 120;
width_mm = 80;
height_mm = 40;
wall_mm = 3;
lid_thickness_mm = 3;
corner_radius_mm = 5;
screw_diameter_mm = 3.2;
post_diameter_mm = 8;
post_hole_mm = 2.7;

module rounded_box(size, radius) {
  hull() {
    for (x = [radius, size[0] - radius]) {
      for (y = [radius, size[1] - radius]) {
        translate([x, y, 0]) cylinder(h = size[2], r = radius);
      }
    }
  }
}

module screw_holes(z_height) {
  for (x = [12, length_mm - 12]) {
    for (y = [12, width_mm - 12]) {
      translate([x, y, -1]) cylinder(h = z_height + 2, d = screw_diameter_mm);
    }
  }
}

module mounting_posts() {
  for (x = [36, 84]) {
    for (y = [24, 56]) {
      translate([x, y, wall_mm]) {
        difference() {
          cylinder(h = 10, d = post_diameter_mm);
          translate([0, 0, -1]) cylinder(h = 12, d = post_hole_mm);
        }
      }
    }
  }
}

module front_panel_cutouts() {
  translate([24, -1, 21]) cube([44, wall_mm + 2, 16]);
  for (x = [78, 90, 102]) {
    translate([x, -1, 27]) rotate([90, 0, 0]) cylinder(h = wall_mm + 2, d = 5);
  }
}

module side_ports() {
  port_labels = ["PWR", "PH", "TURB", "FLOW", "TEMP", "GAS", "ENERGY"];
  for (i = [0:6]) {
    translate([length_mm + 1, 10 + i * 9.5, 21]) rotate([0, 90, 0]) cylinder(h = wall_mm + 2, d = 6);
    translate([length_mm + 0.8, 6 + i * 9.5, 30]) rotate([90, 0, 90])
      linear_extrude(height = 0.6) text(port_labels[i], size = 3, halign = "center");
  }
}

module category_legend() {
  labels = ["FLUID", "SENSOR", "POWER", "CTRL", "DATA"];
  colors = ["#22A8B8", "#D9A42F", "#D66A2F", "#2F8F69", "#1F6FD6"];
  for (i = [0:4]) {
    translate([-42, 18 + i * 8, 8]) {
      color(colors[i]) cube([10, 5, 1]);
      translate([13, 0, 0]) color("#DDE5D8")
        linear_extrude(height = 0.7) text(labels[i], size = 3, valign = "center");
    }
  }
}

module mounting_tabs() {
  for (x = [-17, length_mm + 7]) {
    translate([x, 22, 0]) {
      difference() {
        rounded_box([18, 36, 5], 4);
        translate([9, 18, -1]) cylinder(h = 7, d = 5);
      }
    }
  }
}

module body() {
  difference() {
    union() {
      difference() {
        rounded_box([length_mm, width_mm, height_mm], corner_radius_mm);
        translate([wall_mm, wall_mm, wall_mm])
          rounded_box([length_mm - wall_mm * 2, width_mm - wall_mm * 2, height_mm], corner_radius_mm - 1);
      }
      mounting_posts();
      mounting_tabs();
    }
    screw_holes(height_mm);
    front_panel_cutouts();
    side_ports();
  }

  translate([14, 2.8, 34]) rotate([90, 0, 0])
    linear_extrude(height = 0.8) text("SENSOR IN -> VERIFIED DATA OUT", size = 4);
}

module lid() {
  translate([0, 92, 0]) {
    difference() {
      rounded_box([length_mm, width_mm, lid_thickness_mm], corner_radius_mm);
      screw_holes(lid_thickness_mm);
    }
    translate([length_mm / 2, width_mm / 2 + 16, lid_thickness_mm])
      linear_extrude(height = 0.8)
        text("ECO-CIPHER EDGE VERIFIER", size = 6, halign = "center", valign = "center");
    translate([length_mm - 32, width_mm / 2 - 18, lid_thickness_mm])
      linear_extrude(height = 0.8)
        text("ID: EC-EDGE-001", size = 4, halign = "center", valign = "center");
  }
}

color("#59645E") body();
color("#59645E") lid();
category_legend();

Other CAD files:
dashboard/public/models/eco-cipher-edge-verifier.stl
cad/generated/eco_cipher_edge_verifier_detailed.FCStd
cad/generated/eco_cipher_edge_verifier_detailed.stl

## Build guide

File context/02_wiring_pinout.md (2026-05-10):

# Wiring and Pinout Blueprint

## ESP32 Pin Allocation

| Module | ESP32 Pin | Type |
|---|---|---|
| pH sensor analog output | GPIO 34 | Analog input |
| Turbidity analog output | GPIO 35 | Analog input |
| Flow sensor signal | GPIO 27 | Digital interrupt |
| DS18B20 data | GPIO 4 | OneWire digital |
| OLED SDA | GPIO 21 | I2C SDA |
| OLED SCL | GPIO 22 | I2C SCL |
| Green LED | GPIO 16 | Digital output |
| Yellow LED | GPIO 17 | Digital output |
| Red LED | GPIO 18 | Digital output |
| Buzzer | GPIO 19 | Digital output |
| Push button | GPIO 25 | Digital input |
| Optional MQ-135 | GPIO 32 | Analog input |
| Optional ACS712 | GPIO 33 | Analog input |

## OLED I2C Wiring

```text
OLED VCC → 3.3V
OLED GND → GND
OLED SDA → GPIO 21
OLED SCL → GPIO 22
```

## pH Sensor Wiring

```text
pH Module VCC → 5V
pH Module GND → GND
pH Module AO  → GPIO 34
```

Warning: ESP32 ADC input should not exceed 3.3V. If the sensor output can reach 5V, use a voltage divider.

## Turbidity Sensor Wiring

```text
Turbidity VCC → 5V
Turbidity GND → GND
Turbidity AO  → GPIO 35
```

## Flow Sensor Wiring

```text
Flow Sensor VCC    → 5V
Flow Sensor GND    → GND
Flow Sensor Signal → GPIO 27
```

## DS18B20 Wiring

```text
DS18B20 VCC  → 3.3V
DS18B20 GND  → GND
DS18B20 DATA → GPIO 4
DATA → 4.7kΩ resistor → VCC
```

## LED Indicator Wiring

```text
GPIO 16 → 220Ω resistor → Green LED → GND
GPIO 17 → 220Ω resistor → Yellow LED → GND
GPIO 18 → 220Ω resistor → Red LED → GND
```

## Buzzer Wiring

```text
GPIO 19 → Buzzer +
GND     → Buzzer -
```

Use a transistor driver if your buzzer needs higher current.

## Text Wiring Diagram

```text
                ┌────────────────────────┐
                │         ESP32          │
pH AO       ───▶│ GPIO34 ADC             │
Turb AO     ───▶│ GPIO35 ADC             │
Flow Signal ───▶│ GPIO27 Interrupt       │
Temp Data   ───▶│ GPIO4 OneWire          │
OLED SDA    ───▶│ GPIO21 I2C             │
OLED SCL    ───▶│ GPIO22 I2C             │
Green LED   ◀───│ GPIO16                 │
Yellow LED  ◀───│ GPIO17                 │
Red LED     ◀───│ GPIO18                 │
Buzzer      ◀───│ GPIO19                 │
Button      ───▶│ GPIO25                 │
Wi-Fi       ◀──▶│ Backend / Dashboard    │
                └────────────────────────┘
```

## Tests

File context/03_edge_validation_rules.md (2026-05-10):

# Edge Validation Rules

These are demo thresholds for the prototype, not regulatory standards.

## Status Table

| Parameter | Verified | Warning | Anomaly |
|---|---|---|---|
| pH | 6.5–8.5 | 5.5–6.5 or 8.5–9.5 | <5.5 or >9.5 |
| Turbidity | Low-medium | High | Extreme / sensor error |
| Flow | >0.2 L/min | Unstable | 0 while active |
| Temperature | 20–40°C | 40–50°C | >50°C or sensor error |

## Status Logic

### VERIFIED

Conditions:
- pH between 6.5 and 8.5
- turbidity below warning threshold
- flow rate above minimum threshold
- temperature within expected range

Output:
```text
edge_status = "VERIFIED"
LED = green
buzzer = off
```

### WARNING

Conditions:
- pH slightly outside normal range
- turbidity medium-high
- temperature slightly abnormal

Output:
```text
edge_status = "WARNING"
LED = yellow
buzzer = short beep
```

### ANOMALY

Conditions:
- pH extremely low/high
- flow rate zero during active session
- sensor disconnected
- sudden impossible value jump
- missing payload

Output:
```text
edge_status = "ANOMALY"
LED = red
buzzer = repeated beep
```

## Data Quality Score

Suggested scoring:

```text
data_quality_score =
0.30 sensor_completeness
+ 0.25 normal_range_score
+ 0.20 signal_stability
+ 0.15 device_uptime
+ 0.10 transmission_success
```

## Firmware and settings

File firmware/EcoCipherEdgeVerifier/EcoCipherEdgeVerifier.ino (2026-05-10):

#include <Arduino.h>
#include <WiFi.h>
#include <HTTPClient.h>
#include <ArduinoJson.h>
#include <Wire.h>
#include <Adafruit_GFX.h>
#include <Adafruit_SSD1306.h>
#include <OneWire.h>
#include <DallasTemperature.h>
#include "mbedtls/sha256.h"

// Network and device constants.
const char* WIFI_SSID = "YOUR_WIFI_SSID";
const char* WIFI_PASSWORD = "YOUR_WIFI_PASSWORD";
const char* API_ENDPOINT = "https://example.com/mock/edge-payload";
const char* DEVICE_ID = "EC-EDGE-001";
const char* FACTORY_ALIAS = "Factory_A";

// ESP32 pin allocation from the blueprint package.
const int PH_PIN = 34;
const int TURBIDITY_PIN = 35;
const int FLOW_PIN = 27;
const int ONE_WIRE_PIN = 4;
const int OLED_SDA = 21;
const int OLED_SCL = 22;
const int GREEN_LED_PIN = 16;
const int YELLOW_LED_PIN = 17;
const int RED_LED_PIN = 18;
const int BUZZER_PIN = 19;
const int BUTTON_PIN = 25;
const int MQ135_PIN = 32;
const int ENERGY_PIN = 33;

const unsigned long READ_INTERVAL_MS = 5000;
const float FLOW_CALIBRATION_FACTOR = 7.5; // YF-S201 typical pulses/sec per L/min.
const float PH_ADC_TO_VOLTAGE = 3.3 / 4095.0;
const float PH_NEUTRAL_VOLTAGE = 2.5;
const float PH_SLOPE = -5.7;
const float ADC_MAX_SAFE_VOLTAGE = 3.3;
const float ANALOG_DIVIDER_RATIO = 0.66; // 5V sensor output scaled to ESP32-safe ADC range.

const int TURBIDITY_WARNING_RAW = 650;
const int TURBIDITY_ANOMALY_RAW = 900;
const float FLOW_MIN_LPM = 0.2;
const int GAS_WARNING_RAW = 550;
const int GAS_ANOMALY_RAW = 780;
const float ACS712_ZERO_VOLTAGE = 1.65;
const float ACS712_SENSITIVITY_V_PER_A = 0.185;
const float LINE_VOLTAGE_ESTIMATE = 220.0;

volatile unsigned long flowPulseCount = 0;
unsigned long lastReadAt = 0;
float totalVolumeLiters = 0.0;

OneWire oneWire(ONE_WIRE_PIN);
DallasTemperature temperatureSensors(&oneWire);
Adafruit_SSD1306 display(128, 64, &Wire, -1);

enum EdgeStatus {
  VERIFIED,
  WARNING,
  ANOMALY
};

struct SensorFrame {
  float ph;
  int turbidityRaw;
  float flowRateLpm;
  float temperatureC;
  int gasRaw;
  float gasRiskScore;
  float energyCurrentA;
  float energyPowerW;
  float estimatedVolumeL;
  EdgeStatus status;
  bool anomalyFlag;
  float qualityScore;
  float carbonContextScore;
  float aiMatchConfidence;
  String aiWasteClass;
  String anomalyReasons;
};

void IRAM_ATTR onFlowPulse() {
  flowPulseCount++;
}

String statusToString(EdgeStatus status) {
  if (status == VERIFIED) return "VERIFIED";
  if (status == WARNING) return "WARNING";
  return "ANOMALY";
}

void connectWiFi() {
  WiFi.mode(WIFI_STA);
  WiFi.begin(WIFI_SSID, WIFI_PASSWORD);

  display.clearDisplay();
  display.setCursor(0, 0);
  display.println("BOOTING...");
  display.println("Eco-Cipher Edge");
  display.display();

  unsigned long start = millis();
  while (WiFi.status() != WL_CONNECTED && millis() - start < 15000) {
    delay(300);
  }
}

float readPh() {
  int raw = analogRead(PH_PIN);
  float voltage = raw * PH_ADC_TO_VOLTAGE;
  float sensorVoltage = voltage / ANALOG_DIVIDER_RATIO;
  return 7.0 + ((sensorVoltage - PH_NEUTRAL_VOLTAGE) * PH_SLOPE);
}

int readTurbidityRaw() {
  return analogRead(TURBIDITY_PIN);
}

int readGasRaw() {
  return analogRead(MQ135_PIN);
}

float readEnergyCurrentA() {
  int raw = analogRead(ENERGY_PIN);
  float voltage = (raw * PH_ADC_TO_VOLTAGE) / ANALOG_DIVIDER_RATIO;
  float current = (voltage - ACS712_ZERO_VOLTAGE) / ACS712_SENSITIVITY_V_PER_A;
  return abs(current);
}

float readTemperatureC() {
  temperatureSensors.requestTemperatures();
  return temperatureSensors.getTempCByIndex(0);
}

float calculateFlowRateLpm() {
  noInterrupts();
  unsigned long pulses = flowPulseCount;
  flowPulseCount = 0;
  interrupts();

  float seconds = READ_INTERVAL_MS / 1000.0;
  float pulsesPerSecond = pulses / seconds;
  float lpm = pulsesPerSecond / FLOW_CALIBRATION_FACTOR;
  totalVolumeLiters += lpm * (seconds / 60.0);
  return lpm;
}

String buildAnomalyReasons(float ph, int turbidityRaw, float flowRateLpm, float temperatureC, int gasRaw, float energyPowerW) {
  String reasons = "";
  if (ph < 5.5 || ph > 9.5) reasons += "ph_extreme;";
  if (turbidityRaw >= TURBIDITY_ANOMALY_RAW) reasons += "turbidity_extreme;";
  if (flowRateLpm <= 0.05) reasons += "zero_flow;";
  if (temperatureC == DEVICE_DISCONNECTED_C) reasons += "temperature_sensor_error;";
  if (temperatureC > 50.0) reasons += "temperature_high;";
  if (gasRaw >= GAS_ANOMALY_RAW) reasons += "gas_risk_high;";
  if (energyPowerW <= 1.0) reasons += "energy_context_missing;";
  if (reasons.length() == 0) reasons = "none";
  return reasons;
}

EdgeStatus classifyStatus(float ph, int turbidityRaw, float flowRateLpm, float temperatureC, int gasRaw) {
  bool tempError = temperatureC == DEVICE_DISCONNECTED_C || temperatureC > 50.0;
  bool gasError = gasRaw >= GAS_ANOMALY_RAW;
  bool anomaly = ph < 5.5 || ph > 9.5 || turbidityRaw >= TURBIDITY_ANOMALY_RAW || flowRateLpm <= 0.05 || tempError || gasError;
  if (anomaly) return ANOMALY;

  bool warning = ph < 6.5 || ph > 8.5 || turbidityRaw >= TURBIDITY_WARNING_RAW || flowRateLpm < FLOW_MIN_LPM || temperatureC > 40.0 || gasRaw >= GAS_WARNING_RAW;
  if (warning) return WARNING;

  return VERIFIED;
}

float calculateQualityScore(const SensorFrame& frame) {
  float sensorCompleteness = frame.temperatureC == DEVICE_DISCONNECTED_C ? 0.75 : 1.0;
  float normalRangeScore = frame.status == VERIFIED ? 1.0 : frame.status == WARNING ? 0.62 : 0.28;
  float stability = frame.turbidityRaw >= TURBIDITY_ANOMALY_RAW ? 0.45 : frame.turbidityRaw >= TURBIDITY_WARNING_RAW ? 0.72 : 0.92;
  float uptime = 0.96;
  float transmission = WiFi.status() == WL_CONNECTED ? 0.98 : 0.2;

  return 0.30 * sensorCompleteness + 0.25 * normalRangeScore + 0.20 * stability + 0.15 * uptime + 0.10 * transmission;
}

float calculateGasRiskScore(int gasRaw) {
  return constrain(gasRaw / 1023.0, 0.0, 1.0);
}

float calculateCarbonContextScore(const SensorFrame& frame) {
  float flowContext = constrain(frame.flowRateLpm / 5.0, 0.0, 1.0);
  float energyContext = constrain(frame.energyPowerW / 1000.0, 0.0, 1.0);
  float gasPenalty = 1.0 - frame.gasRiskScore;
  return 0.35 * flowContext + 0.30 * energyContext + 0.20 * gasPenalty + 0.15 * frame.qualityScore;
}

String classifyWasteForAi(const SensorFrame& frame) {
  if (frame.status == ANOMALY) return "manual_review_required";
  if (frame.gasRiskScore > 0.55) return "emission_sensitive_stream";
  if (frame.turbidityRaw >= TURBIDITY_WARNING_RAW) return "organic_turbid_wastewater";
  if (frame.energyPowerW > 600.0) return "energy_linked_process_stream";
  return "neutral_wastewater_stream";
}

float calculateAiMatchConfidence(const SensorFrame& frame) {
  float statusFactor = frame.status == VERIFIED ? 0.96 : frame.status == WARNING ? 0.72 : 0.38;
  return constrain(0.55 * frame.qualityScore + 0.25 * frame.carbonContextScore + 0.20 * statusFactor, 0.0, 1.0);
}

SensorFrame readSensors() {
  SensorFrame frame;
  frame.ph = readPh();
  frame.turbidityRaw = readTurbidityRaw();
  frame.flowRateLpm = calculateFlowRateLpm();
  frame.temperatureC = readTemperatureC();
  frame.gasRaw = readGasRaw();
  frame.gasRiskScore = calculateGasRiskScore(frame.gasRaw);
  frame.energyCurrentA = readEnergyCurrentA();
  frame.energyPowerW = frame.energyCurrentA * LINE_VOLTAGE_ESTIMATE;
  frame.estimatedVolumeL = totalVolumeLiters;
  frame.status = classifyStatus(frame.ph, frame.turbidityRaw, frame.flowRateLpm, frame.temperatureC, frame.gasRaw);
  frame.anomalyFlag = frame.status == ANOMALY;
  frame.qualityScore = calculateQualityScore(frame);
  frame.carbonContextScore = calculateCarbonContextScore(frame);
  frame.aiWasteClass = classifyWasteForAi(frame);
  frame.aiMatchConfidence = calculateAiMatchConfidence(frame);
  frame.anomalyReasons = buildAnomalyReasons(frame.ph, frame.turbidityRaw, frame.flowRateLpm, frame.temperatureC, frame.gasRaw, frame.energyPowerW);
  return frame;
}

String sha256(String input) {
  byte hash[32];
  mbedtls_sha256_context ctx;
  mbedtls_sha256_init(&ctx);
  mbedtls_sha256_starts(&ctx, 0);
  mbedtls_sha256_update(&ctx, (const unsigned char*)input.c_str(), input.length());
  mbedtls_sha256_finish(&ctx, hash);
  mbedtls_sha256_free(&ctx);

  String output = "";
  for (byte index = 0; index < 32; index++) {
    if (hash[index] < 16) output += "0";
    output += String(hash[index], HEX);
  }
  return output;
}

String buildPayload(const SensorFrame& frame) {
  StaticJsonDocument<512> doc;
  doc["device_id"] = DEVICE_ID;
  doc["factory_alias"] = FACTORY_ALIAS;
  doc["timestamp"] = String(millis());
  doc["sensor_type"] = "wastewater_edge_verifier";
  doc["ph"] = round(frame.ph * 100.0) / 100.0;
  doc["turbidity_raw"] = frame.turbidityRaw;
  doc["flow_rate_lpm"] = round(frame.flowRateLpm * 100.0) / 100.0;
  doc["temperature_c"] = round(frame.temperatureC * 10.0) / 10.0;
  doc["gas_raw"] = frame.gasRaw;
  doc["gas_risk_score"] = round(frame.gasRiskScore * 100.0) / 100.0;
  doc["energy_current_a"] = round(frame.energyCurrentA * 100.0) / 100.0;
  doc["energy_power_w"] = round(frame.energyPowerW * 10.0) / 10.0;
  doc["estimated_volume_l"] = round(frame.estimatedVolumeL * 100.0) / 100.0;
  doc["edge_status"] = statusToString(frame.status);
  doc["anomaly_flag"] = frame.anomalyFlag;
  doc["data_quality_score"] = round(frame.qualityScore * 100.0) / 100.0;
  doc["carbon_context_score"] = round(frame.carbonContextScore * 100.0) / 100.0;
  doc["ai_waste_class"] = frame.aiWasteClass;
  doc["ai_match_confidence"] = round(frame.aiMatchConfidence * 100.0) / 100.0;
  doc["anomaly_reasons"] = frame.anomalyReasons;

  String withoutHash;
  serializeJson(doc, withoutHash);
  doc["payload_hash"] = sha256(withoutHash);

  String payload;
  serializeJson(doc, payload);
  return payload;
}

void updateOutputs(const SensorFrame& frame) {
  digitalWrite(GREEN_LED_PIN, frame.status == VERIFIED ? HIGH : LOW);
  digitalWrite(YELLOW_LED_PIN, frame.status == WARNING ? HIGH : LOW);
  digitalWrite(RED_LED_PIN, frame.status == ANOMALY ? HIGH : LOW);

  if (frame.status == ANOMALY) {
    tone(BUZZER_PIN, 2200, 350);
  } else if (frame.status == WARNING) {
    tone(BUZZER_PIN, 1500, 120);
  } else {
    noTone(BUZZER_PIN);
  }

  display.clearDisplay();
  display.setCursor(0, 0);
  display.print("Device: ");
  display.println(DEVICE_ID);
  display.print("Status: ");
  display.println(statusToString(frame.status));
  display.print("pH ");
  display.print(frame.ph, 2);
  display.print("  T ");
  display.print(frame.temperatureC, 1);
  display.println("C");
  display.print("Turb ");
  display.print(frame.turbidityRaw);
  display.print(" Flow ");
  display.print(frame.flowRateLpm, 1);
  display.println("L/m");
  display.print("Q ");
  display.print(frame.qualityScore * 100, 0);
  display.print("% AI ");
  display.print(frame.aiMatchConfidence * 100, 0);
  display.println("%");
  display.display();
}

void sendPayload(const String& payload) {
  if (WiFi.status() != WL_CONNECTED) {
    connectWiFi();
  }

  if (WiFi.status() != WL_CONNECTED) {
    return;
  }

  HTTPClient http;
  http.begin(API_ENDPOINT);
  http.addHeader("Content-Type", "application/json");
  http.POST(payload);
  http.end();
}

void setup() {
  Serial.begin(115200);
  pinMode(GREEN_LED_PIN, OUTPUT);
  pinMode(YELLOW_LED_PIN, OUTPUT);
  pinMode(RED_LED_PIN, OUTPUT);
  pinMode(BUZZER_PIN, OUTPUT);
  pinMode(BUTTON_PIN, INPUT_PULLUP);
  pinMode(FLOW_PIN, INPUT_PULLUP);
  attachInterrupt(digitalPinToInterrupt(FLOW_PIN), onFlowPulse, RISING);

  Wire.begin(OLED_SDA, OLED_SCL);
  display.begin(SSD1306_SWITCHCAPVCC, 0x3C);
  display.setTextSize(1);
  display.setTextColor(SSD1306_WHITE);

  temperatureSensors.begin();
  connectWiFi();
}

void loop() {
  if (millis() - lastReadAt < READ_INTERVAL_MS && digitalRead(BUTTON_PIN) == HIGH) {
    return;
  }

  lastReadAt = millis();
  SensorFrame frame = readSensors();
  updateOutputs(frame);
  String payload = buildPayload(frame);
  Serial.println(payload);
  sendPayload(payload);
}
